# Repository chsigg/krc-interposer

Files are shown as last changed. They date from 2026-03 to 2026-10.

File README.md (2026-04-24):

# KRC Interposer

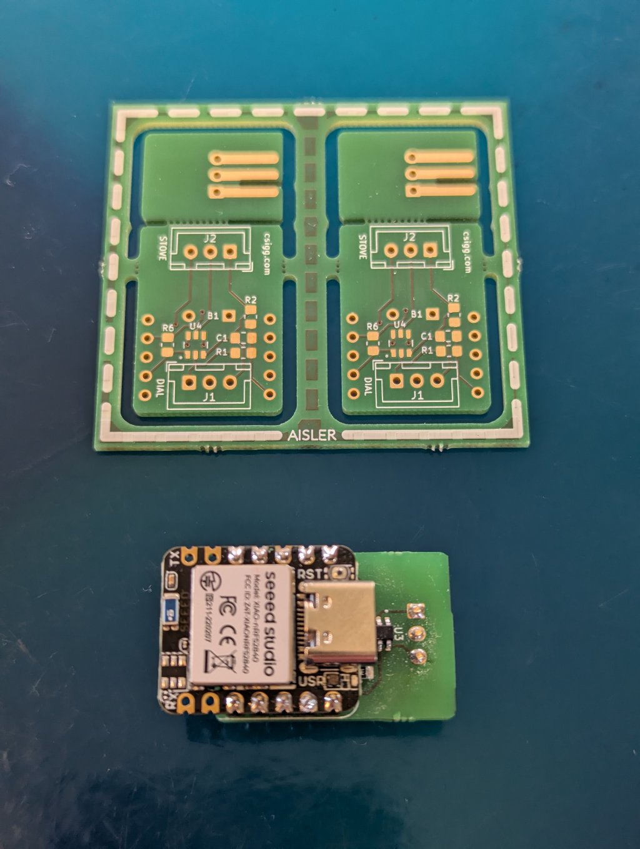
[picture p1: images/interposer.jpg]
KRC Interposer


The KRC Interposer is a hardware intermediary that converts a standard induction stove dial into a closed-loop temperature controller. It is designed for use with Kuhn Rikon Comfort (KRC) cookware, such as the Duromatic pressure cooker or Hotpan. The interposer intercepts the analog signal from the stove’s physical knob, connects to the cookware lid via Bluetooth Low Energy (BLE), and regulates the stove's power output to maintain a target temperature.

The system is built around the Seeed Studio XIAO nRF52840 microcontroller. It is designed to have no effect during standard stove operation, activating only when smart temperature control is initiated.

## Operating Modes

### Wake and Connection
Smart features are triggered by turning the dial to the stove's built-in **Boil Mode** (below 0). The resulting resistance change is detected by a companion PIC microcontroller, which then wakes the XIAO via serial communication (UART RX).

The microcontroller then takes control of the analog switch, routing its own filtered PWM output to the stove in place of the physical dial. It enters a scanning state to locate a Kuhn Rikon Comfort lid via BLE. Upon successful connection, the device emits an audible beep.

### Active Temperature Control
Once connected, the physical dial's positions are repurposed:
*   **Off:** Pauses heating and acts as an "Off" switch.
*   **1 to 9:** Maps to a target temperature range between 30°C and 120°C.

The interposer reads the current temperature from the BLE lid and uses a proportional-predictive thermal model (with feed-forward heat loss compensation) to simulate the required analog voltage to the stove. It automatically utilizes the stove's native hardware boost modes for rapid heating. A slew-rate limiter ensures smooth voltage transitions to prevent hardware faults on the stove's internal controller.

### Safety and Shutdown
*   **Signal Loss:** If the BLE connection drops, the interposer emits a warning beep and eventually reduces stove power to a safe minimum until the connection is restored.
*   **Power Off:** Turning the dial to **Off** initiates a 5-second shutdown timer. After this delay, the XIAO powers down completely, and the analog switch reconnects the physical dial to the stove.

### Telemetry (Optional)
The interposer concurrently operates as a BLE Peripheral. A [companion app](http://github.com/chsigg/krc-app) can connect to receive real-time telemetry, including measured temperature, target temperature, and diagnostic logs.

### Video of the interposer in action
KRC Interposer in action (https://www.youtube.com/watch?v=Ic5JpSSapok)

## Hardware Overview

The interposer board acts as a man-in-the-middle interface between a Miele stove and its physical 10kΩ potentiometer dial. It allows a Seeed Studio XIAO nRF52840 to either passively monitor the dial or actively override the signal to control the stove.

### Dial Interface

The physical dial on the stove functions as a potentiometer, outputting a variable analog voltage to the stove's control electronics:

*   **Off:** The signal line is left floating.
*   **1 to 9:** Standard heating power levels.
*   **Below 0 (Boil Mode):** Resistance drops to a minimum. The stove interprets this as a command to apply maximum power for a set duration before returning to the dial's indicated level.
*   **Above 9 (Boost Mode):** Activates discrete high-power boost levels.

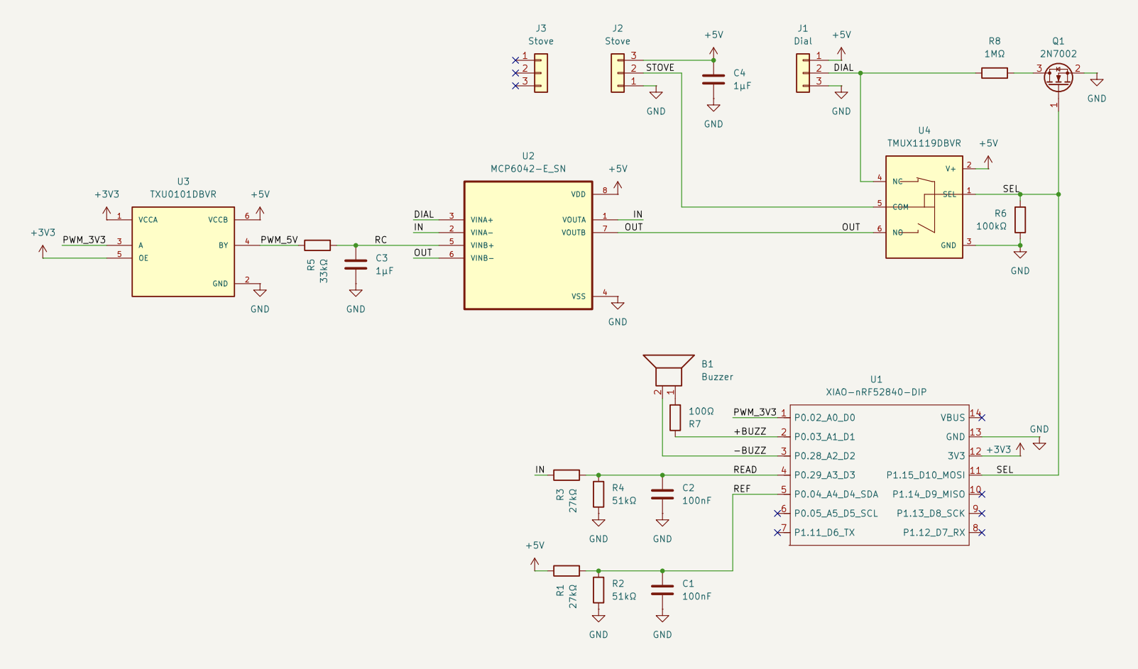
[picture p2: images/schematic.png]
Schematic


### Core Subsystems

*   **Signal Routing (TMUX1119):** A 5V SPDT analog switch toggles the stove's sensor input. In Bypass Mode (default), it connects the stove directly to the physical dial. In Control Mode, it connects the stove to the synthetic control signal.
*   **ADC Sensing:** Voltage dividers (27kΩ / 51kΩ) step the 5V dial and stove signals down to safe 3.3V levels for the XIAO's ADC. High-impedance values limit parasitic draw to ~30µA, as the stove's 5V line is a current-limited sensor reference (max ~1.5mA) and will collapse under standard loads.
*   **Synthetic Signal Generation (TXU0101 & MCP6042):** The XIAO generates a 3.3V PWM signal. A TXU0101 level shifter steps this up to 5V. An RC filter and an MCP6042 micropower op-amp buffer the signal into a clean analog DC voltage for the stove.
*   **Switched Pull-Down:** A pull-down resistor prevents the op-amp input from floating when the dial is turned off. An N-channel MOSFET disconnects this resistor during Bypass Mode to avoid tripping the stove's safety interlocks.
*   **Power Isolation:** The XIAO must be powered independently via USB. The stove's 5V reference rail cannot supply the current required for microcontroller boot or radio transmission.

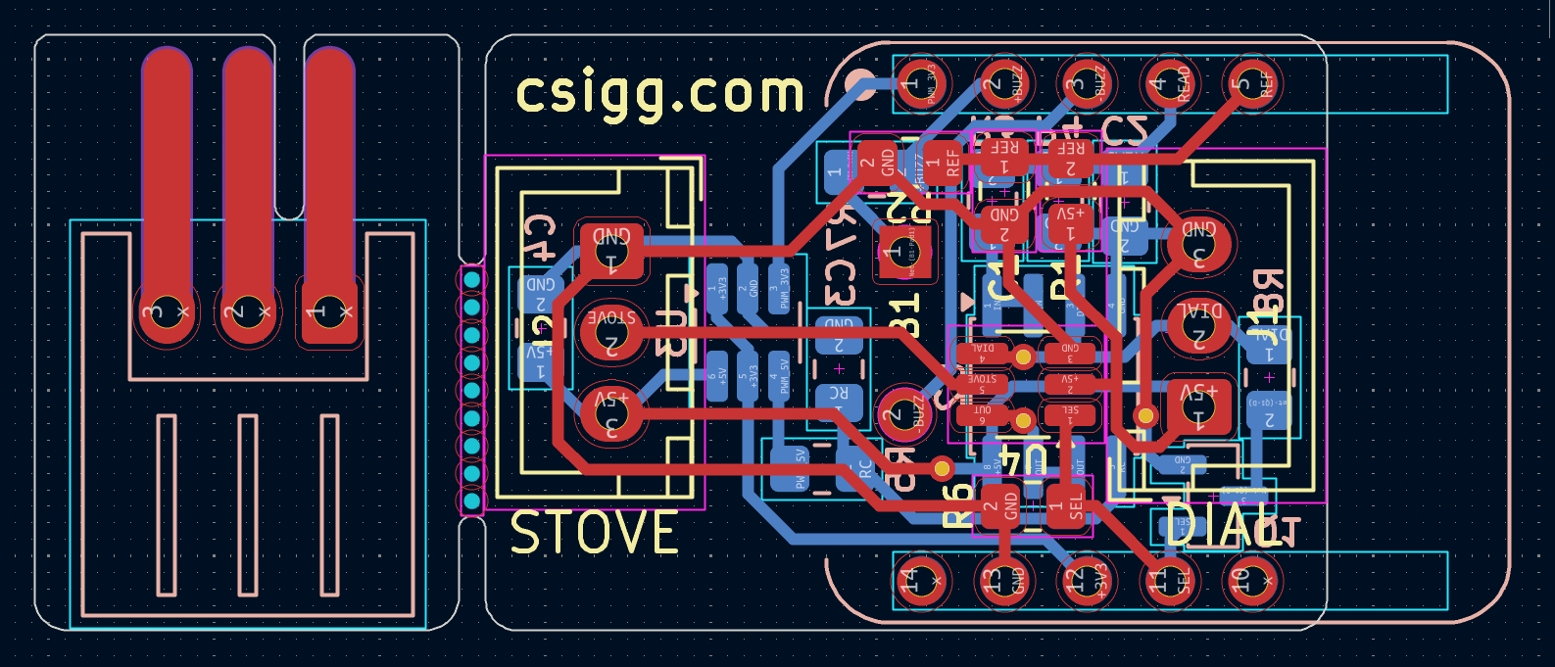
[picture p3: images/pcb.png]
PCB


## Development

The project is built using PlatformIO and the Arduino framework.

### Build
Compile the firmware for the XIAO nRF52840:
```bash
pio run
```

### Testing
Unit tests are implemented with `doctest` and `ArduinoFake` to run the logic modules natively on the host machine.
```bash
pio test -e native
```

## Software Architecture

The firmware enforces strict separation between high-level control logic and hardware interfaces to facilitate native testing.

*   **`StoveSupervisor`:** A state machine managing the high-level operational states (`SCANNING`, `CONNECTED`, `ACTIVE`, `DISCONNECTED`). It handles timers, user feedback, and logic for engaging hardware boost modes.
*   **`ThermalController`:** Implements the closed-loop temperature regulation using a proportional-predictive model and ambient heat loss compensation.
*   **`StoveActuator`:** Translates logical throttle requests into physical PWM signals. It includes a slew-rate limiter (`0.001/ms`) and minimum voltage clamping to maintain hardware stability on the stove's input line.
*   **`TrendAnalyzer`:** Buffers BLE temperature readings to calculate predicted future temperatures (compensating for system thermal lag) and the current rate of change.
*   **`BleThermometer` (BLE Central):** Scans for and connects to supported KRC lids, passing incoming temperature data to the `TrendAnalyzer`.
*   **`BleTelemetry` (BLE Peripheral):** Broadcasts internal state data and buffered logs to connected clients.
*   **Hardware Abstractions:** Interfaces like `DialSensor` and `StoveActuator` or 'Led' decouple the core logic from Arduino-specific functions, allowing execution against mock objects in the test suite.

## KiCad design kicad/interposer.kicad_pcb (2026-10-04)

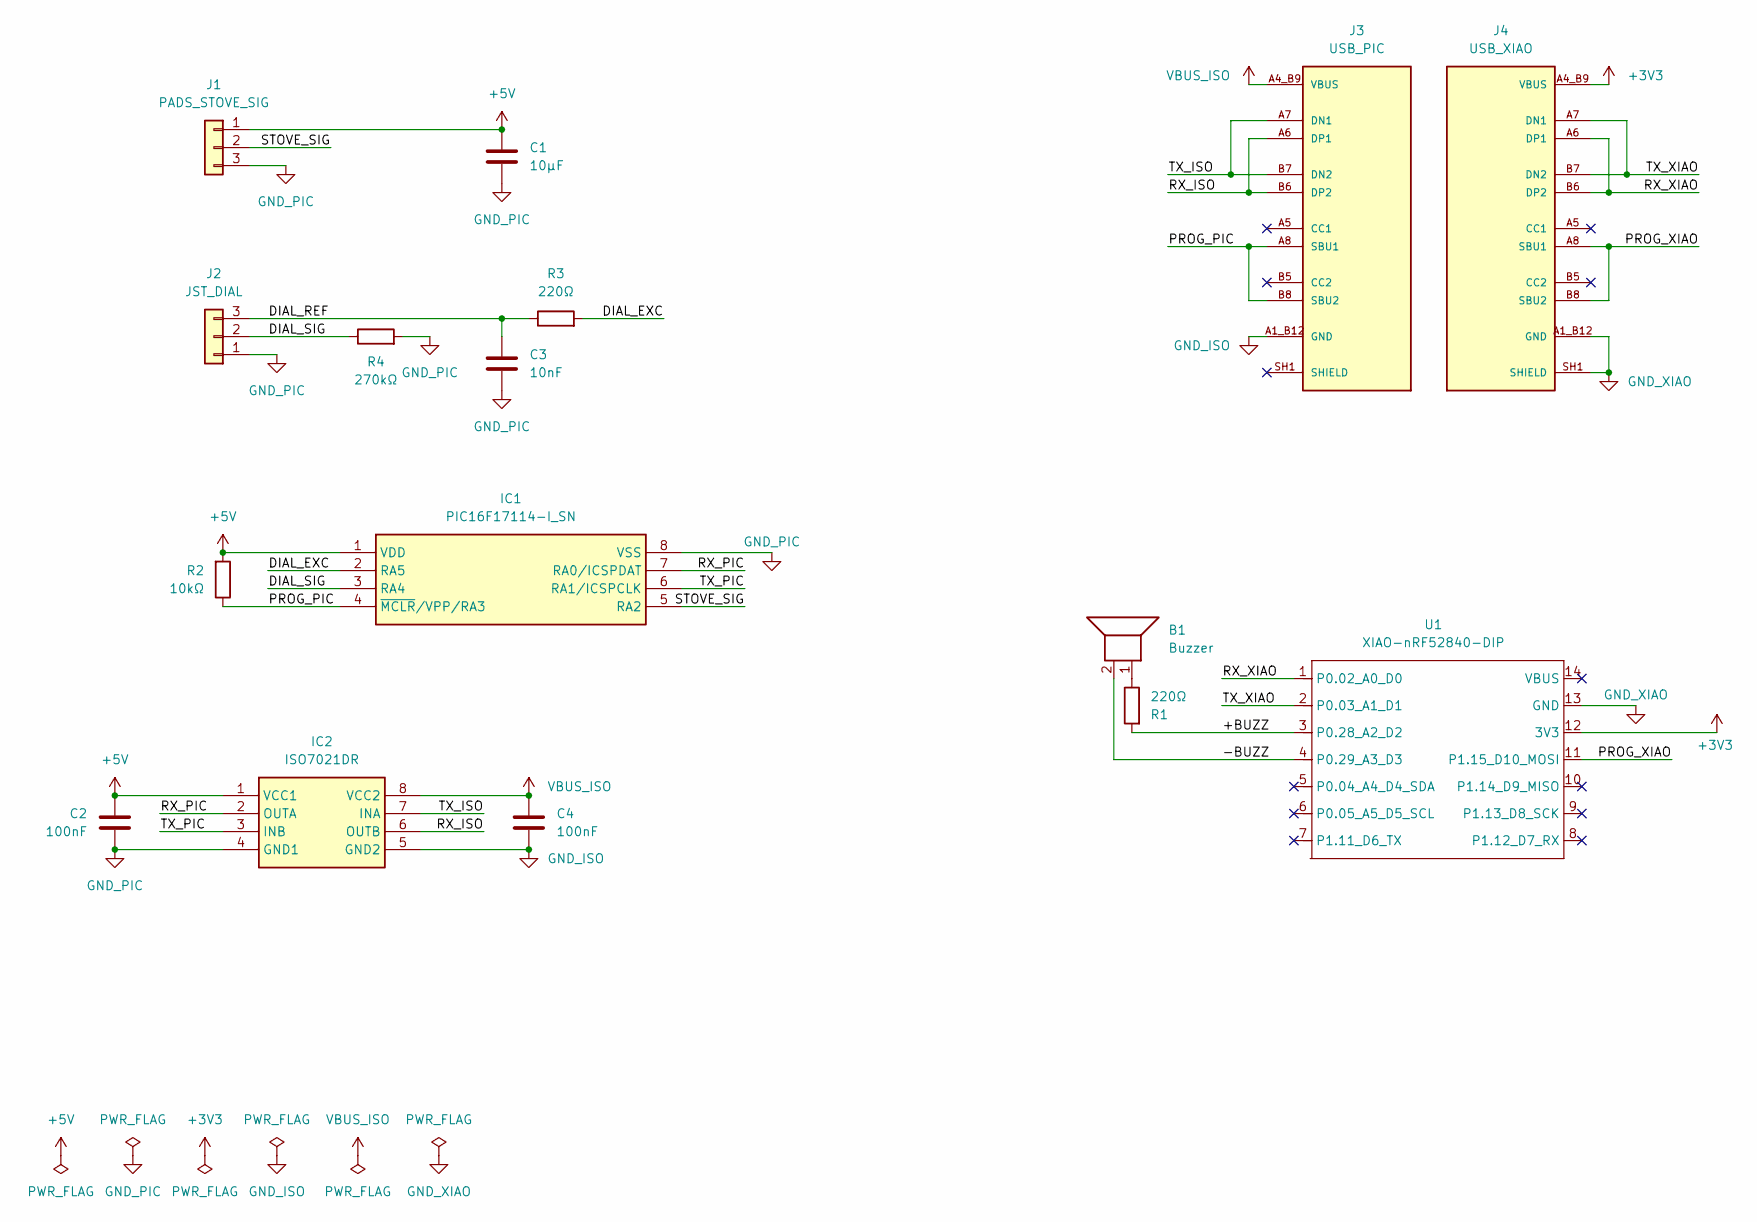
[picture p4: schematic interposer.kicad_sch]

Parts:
B1: Buzzer; Buzzer_Murata_PKLCS1212E
C1: 10µF; C_0805_2012Metric_Pad1.18x1.45mm_HandSolder
C2, C4: 100nF; C_0805_2012Metric_Pad1.18x1.45mm_HandSolder
C3: 10nF; C_0805_2012Metric_Pad1.18x1.45mm_HandSolder
IC1: PIC16F17114-I_SN; SOIC-8_3.9x4.9mm_P1.27mm; Manufacturer_Part_Number PIC16F17114-I/SN; Mouser Part Number 579-PIC16F17114-I/SN
IC2: ISO7021DR; SOIC-8_3.9x4.9mm_P1.27mm; Manufacturer_Part_Number ISO7021DR; Mouser Part Number 595-ISO7021DR
J1: PADS_STOVE_SIG; RAST 2.5 Pads
J2: JST_DIAL; JST_XH_S3B-XH-A_1x03_P2.50mm_Horizontal
J3: USB_PIC; SAMESKY_UJ20-C-H-G-SMT-P16-TR; PARTREV 1.0
J4: USB_XIAO; SAMESKY_UJ20-C-H-G-SMT-P16-TR; PARTREV 1.0
R1, R3: 220Ω; R_0805_2012Metric_Pad1.20x1.40mm_HandSolder
R2: 10kΩ; R_0805_2012Metric_Pad1.20x1.40mm_HandSolder
R4: 270kΩ; R_0805_2012Metric_Pad1.20x1.40mm_HandSolder
U1: XIAO-nRF52840-DIP

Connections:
+3V3: J4.A4_B9 (VBUS), J4.B4_A9 (VBUS), U1.12 (3V3)
+5V: C1.1, C2.1, IC1.1 (VDD), IC2.1 (VCC1), J1.1, R2.2
/+BUZZ: R1.2, U1.3 (P0.28_A2_D2)
/-BUZZ: B1.2, U1.4 (P0.29_A3_D3)
/DIAL_EXC: IC1.2 (RA5), R3.2
/DIAL_REF: C3.1, J2.3, R3.1
/DIAL_SIG: IC1.3 (RA4), J2.2, R4.1
/PROG_PIC: IC1.4 (~MCLR/VPP/RA3), J3.A8 (SBU1), J3.B8 (SBU2), R2.1
/PROG_XIAO: J4.A8 (SBU1), J4.B8 (SBU2), U1.11 (P1.15_D10_MOSI)
/RX_ISO: IC2.6 (OUTB), J3.A6 (DP1), J3.B6 (DP2)
/RX_PIC: IC1.7 (RA0/ICSPDAT), IC2.2 (OUTA)
/RX_XIAO: J4.A6 (DP1), J4.B6 (DP2), U1.1 (P0.02_A0_D0)
/STOVE_SIG: IC1.5 (RA2), J1.2
/TX_ISO: IC2.7 (INA), J3.A7 (DN1), J3.B7 (DN2)
/TX_PIC: IC1.6 (RA1/ICSPCLK), IC2.3 (INB)
/TX_XIAO: J4.A7 (DN1), J4.B7 (DN2), U1.2 (P0.03_A1_D1)
GND_ISO: C4.2, IC2.5 (GND2), J3.A1_B12 (GND), J3.A12_B1 (GND)
GND_PIC: C1.2, C2.2, C3.2, IC1.8 (VSS), IC2.4 (GND1), J1.3, J2.1, R4.2
GND_XIAO: J4.A1_B12 (GND), J4.A12_B1 (GND), J4.SH1 (SHIELD), J4.SH2 (SHIELD), J4.SH3 (SHIELD), J4.SH4 (SHIELD), U1.13 (GND)
unnamed: B1.1, R1.1
VBUS_ISO: C4.1, IC2.8 (VCC2), J3.A4_B9 (VBUS), J3.B4_A9 (VBUS)

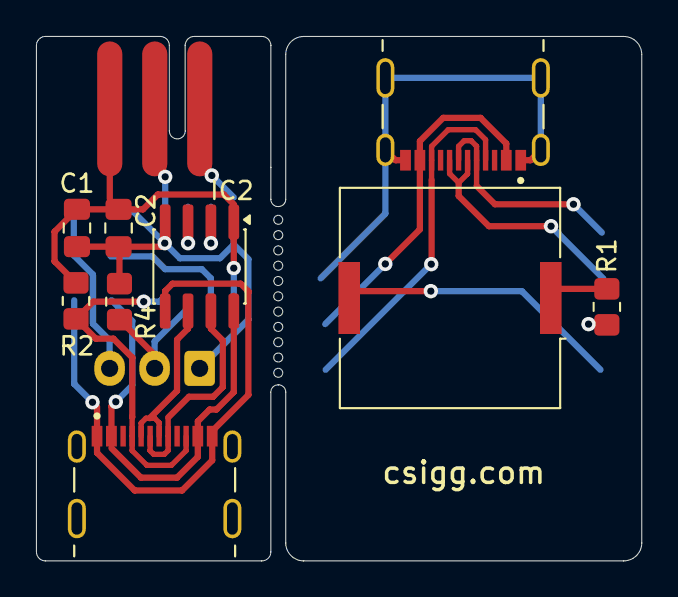
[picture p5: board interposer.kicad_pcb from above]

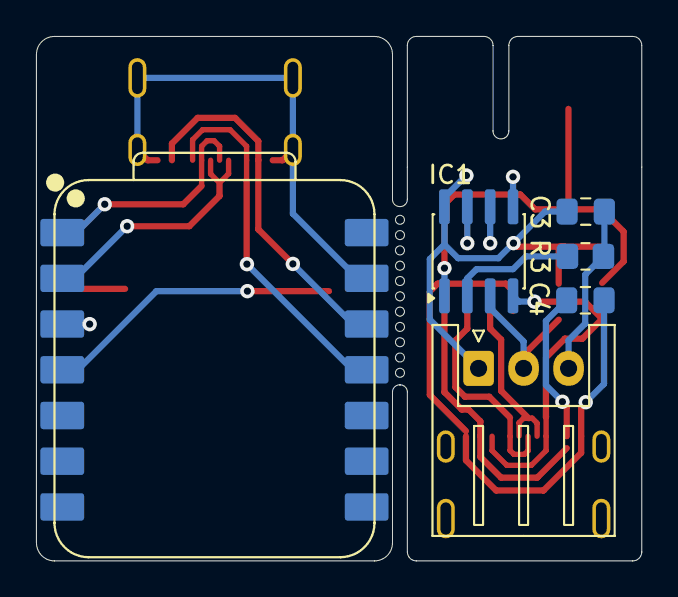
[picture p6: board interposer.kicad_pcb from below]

Board: 2 copper layers, 33.6 x 29.1 mm, 16 parts (6 on the bottom side), 21 nets.

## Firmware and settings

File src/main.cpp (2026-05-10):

#include <bluefruit.h>
#include <nrf_lpcomp.h>
#include <nrf_pwm.h>

#include "ArduinoBuzzer.h"
#include "ArduinoLed.h"
#include "ArduinoLogger.h"
#include "ArduinoUart.h"
#include "Beeper.h"
#include "BleTelemetry.h"
#include "BleThermometer.h"
#include "StoveController.h"
#include "StoveDial.h"
#include "StoveSupervisor.h"
#include "ThermalController.h"
#include "TimestampLogger.h"
#include "TrendAnalyzer.h"

void delayUs(uint32_t us) { delayMicroseconds(us); }

constexpr int kUartTxPin = D0;
constexpr int kUartRxPin = D1;
constexpr int kBuzzerPPin = A2;
constexpr int kBuzzerNPin = A3;

static void shutdown();

// --- Hardware Instantiation ---

// Tee stream for logging to Serial and BLE
BufferedLogger buffered_logger(1024);
ArduinoLogger arduino_logger(buffered_logger);
TimestampLogger timestamp_logger(arduino_logger);
Logger &Log = timestamp_logger;

// UART communication with PIC
ArduinoUart uart(kUartRxPin, kUartTxPin);

// Configuration
ThrottleConfig throttle_config;
ThermalConfig thermal_config;

uint32_t dial_off_start_ms = 0;

// Actuators
StoveController controller(uart, throttle_config);

// Sensors
StoveDial dial(uart, throttle_config);

// Feedback
ArduinoBuzzer buzzer(NRF_PWM3, kBuzzerPPin, kBuzzerNPin);
Beeper beeper(buzzer);
ArduinoLed red_led(LED_RED);
ArduinoLed green_led(LED_GREEN);

// Logic Modules
TrendAnalyzer analyzer;
ThermalController thermal_controller(analyzer, thermal_config);

// BLE Modules
BleThermometer thermometer(analyzer);
BleTelemetry telemetry(thermal_controller, analyzer, buffered_logger);

// Supervisor (bypassing is handled internally by uart)
StoveConfig stove_config;
StoveSupervisor supervisor(dial, controller, thermal_controller, beeper,
                           analyzer, stove_config, throttle_config);

void setup() {
  uart.begin();

  for (int pin : {D4, D5, D6, D7, D8, D9, D10}) {
    pinMode(pin, INPUT_PULLDOWN);
  }

  analogWriteResolution(ADC_RESOLUTION);

  red_led.begin();
  green_led.begin();
  green_led.set(1.0f);

  Serial.begin(115200);

  Bluefruit.configPrphConn(BLE_GATT_ATT_MTU_MAX, BLE_GAP_EVENT_LENGTH_DEFAULT,
                           BLE_GATTS_HVN_TX_QUEUE_SIZE_DEFAULT,
                           BLE_GATTC_WRITE_CMD_TX_QUEUE_SIZE_DEFAULT);
  Bluefruit.begin(1, 1);
  Bluefruit.autoConnLed(false);
  Bluefruit.setTxPower(8);
  Bluefruit.setName("KRC Interposer");

  buzzer.begin();
  beeper.beep(Beeper::Signal::POWER_ON);

  while (!Serial && millis() < 1000) {
    beeper.update();
    delay(10);
  }
  Log << "KRC Interceptor Starting...\n";

  thermometer.begin();
  telemetry.begin();
  green_led.set(0.0f);
}

void loop() {
  if (dial.isOff()) {
    if (millis() - dial_off_start_ms > 5000) {
      return shutdown();
    }
  } else {
    dial_off_start_ms = millis();
  }

  uart.update();
  thermometer.update();
  supervisor.update();
  red_led.set(thermal_controller.getPower());
  telemetry.update();
  delay(20);
}

static void shutdown() {
  red_led.set(1.0f);
  beeper.beep(Beeper::Signal::POWER_OFF);
  while (!beeper.isIdle()) {
    delay(10);
    beeper.update();
  }

  Log << "Powering off...\n";

  thermometer.end();
  telemetry.update();
  telemetry.end();
  uart.end();

  Serial.flush();
  Serial.end();

  for (auto pwm : {NRF_PWM0, NRF_PWM1, NRF_PWM2, NRF_PWM3}) {
    nrf_pwm_disable(pwm);
  }
  for (int pin : {kBuzzerPPin, kBuzzerNPin}) {
    pinMode(pin, INPUT_PULLDOWN);
  }
  for (int pin : {kUartTxPin, LED_RED, LED_GREEN, LED_BLUE}) {
    pinMode(pin, INPUT_PULLUP);
  }

  // Set up System OFF Boot trigger based on UART RX Start Bit (High-to-Low)
  nrf_gpio_cfg_sense_input(g_ADigitalPinMap[kUartRxPin], NRF_GPIO_PIN_PULLUP,
                           NRF_GPIO_PIN_SENSE_LOW);
  sd_power_system_off();
}

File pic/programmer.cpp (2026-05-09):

#include <Arduino.h>
#include <Adafruit_TinyUSB.h>
#include <iterator>
#include "firmware_data.h"

// Hardware Definitions
const int PIN_MCLR = D10;
const int PIN_ICSPDAT = D0;
const int PIN_ICSPCLK = D1;

// Microchip ICSP Timing Specs (PIC16F17114)
const uint32_t T_ENTH_US = 500;
const uint32_t T_DLY_US = 100;
const uint32_t T_ERAB_MS = 15;
const uint32_t T_PINT_MS = 10;
const uint32_t T_CLOCK_US = 5;

// --- Low-Level Bit-Bang Helpers ---

// Explicit delays to satisfy PIC timing parameter constraints.
inline void tickDelay() {
    delayMicroseconds(T_CLOCK_US);
}

void bitBangWrite(uint32_t data, int num_bits) {
    // Set as output to drive the PIC
    pinMode(PIN_ICSPDAT, OUTPUT);

    // PIC Expects MSb First for command and payload data fields
    for (int i = num_bits - 1; i >= 0; i--) {
        digitalWrite(PIN_ICSPDAT, (data >> i) & 0x01);

        // Data changes on rising edge, latched on falling edge.
        // Verified timing: PIC samples strictly during stable HIGH period.
        tickDelay();
        digitalWrite(PIN_ICSPCLK, HIGH);
        tickDelay();
        digitalWrite(PIN_ICSPCLK, LOW);
    }

    // Ensure line returns to safe state
    digitalWrite(PIN_ICSPDAT, LOW);
}

uint32_t bitBangRead(int num_bits) {
    uint32_t val = 0;

    // Set to high-impedance input to let the PIC drive
    pinMode(PIN_ICSPDAT, INPUT);

    // Extra explicit turnaround delay to ensure bus yields
    delayMicroseconds(5);

    for (int i = num_bits - 1; i >= 0; i--) {
        tickDelay();
        digitalWrite(PIN_ICSPCLK, HIGH);

        // Standard consensus: Sample strictly inside the HIGH clock phase.
        // We delay slightly into the High phase to sample at dead-center stability.
        tickDelay();

        if (digitalRead(PIN_ICSPDAT)) {
            val |= (1UL << i);
        }

        digitalWrite(PIN_ICSPCLK, LOW);
    }

    // Reclaim the line for subsequent commands
    pinMode(PIN_ICSPDAT, OUTPUT);
    digitalWrite(PIN_ICSPDAT, LOW);

    return val;
}

// --- Core ICSP Primitives ---

void sendCommand(uint8_t cmd) {
    bitBangWrite(cmd, 8);
    delayMicroseconds(T_DLY_US);
}

void sendPayload(uint16_t data) {
    // 24-bit frame: [Start=0 (bit 23)] [Pad=000000 (bits 22-17)] [Data=16 bits (bits 16-1)] [Stop=0 (bit 0)]
    // The data is explicitly 16 bits, left-shifted by 1 to make space for the stop bit.
    // This construction preserves Bit 15 of the address (e.g. 0x8000 range), which previous code truncated.
    uint32_t frame = (static_cast<uint32_t>(data) & 0xFFFF) << 1;

    bitBangWrite(frame, 24);
    delayMicroseconds(T_DLY_US);
}

uint16_t readPayload() {
    // Read 24-bit frame from the device
    uint32_t frame = bitBangRead(24);

    // Extract the 16 bits contained in frame bits 16 through 1.
    // The 14-bit payload is safely within these 16 bits.
    uint16_t data = (frame >> 1) & 0xFFFF;

    delayMicroseconds(T_DLY_US);
    return data;
}

// --- Programming State Machine ---

bool enterLvp() {
    digitalWrite(PIN_ICSPCLK, LOW);
    digitalWrite(PIN_ICSPDAT, LOW);
    pinMode(PIN_ICSPCLK, OUTPUT);
    pinMode(PIN_ICSPDAT, OUTPUT);

    // Ensure MCLR holds PIC in reset
    digitalWrite(PIN_MCLR, LOW);
    delayMicroseconds(T_ENTH_US);

    // Shift in 32-bit LVP Key: 0x4D434850 strictly MSb First
    bitBangWrite(0x4D, 8);
    bitBangWrite(0x43, 8);
    bitBangWrite(0x48, 8);
    bitBangWrite(0x50, 8);

    delayMicroseconds(T_DLY_US);
    return true;
}

void exitLvp() {
    digitalWrite(PIN_MCLR, HIGH);
}

void bulkErase() {
    sendCommand(0x80);      // Load PC Address
    sendPayload(0x0000);    // Point to Flash

    sendCommand(0x18);      // Bulk Erase
    sendPayload(0x000A);    // Bit 1 = Flash, Bit 3 = Config

    delay(T_ERAB_MS);
}

void writeMemory(uint16_t start_addr, const uint16_t* data, size_t count, uint32_t row_size) {
    sendCommand(0x80);
    sendPayload(start_addr);

    for (size_t i = 0; i < count; i++) {
        bool end_of_row = (i + 1) % row_size == 0;
        sendCommand(end_of_row ? 0x00 : 0x02);
        sendPayload(data[i]);

        if (end_of_row) {
            sendCommand(0xE0); // Begin Internally Timed Programming
            delay(T_PINT_MS);

            if (i < count - 1) {
                sendCommand(0xF8); // Increment Address
            }
        }
    }
}

void verifyMemory(uint16_t start_addr, const uint16_t* data, size_t count) {
    sendCommand(0x80);
    sendPayload(start_addr);

    for (size_t i = 0; i < count; i++) {
        sendCommand(0xFE);  // Read Data and Increment PC
        uint16_t read_val = readPayload();
        uint16_t current_addr = start_addr + i;

        if (read_val != data[i]) {
            Serial.printf("Verify Failed at 0x%04X: Expected 0x%04X, Got 0x%04X\n", current_addr, data[i], read_val);
            return;
        }
    }
    Serial.printf("Verification Successful!\n");
}

// --- Arduino Framework ---

void setup() {
    Serial.begin(115200);
    while(!Serial);

    pinMode(PIN_MCLR, OUTPUT);
    digitalWrite(PIN_MCLR, HIGH); // Hold PIC in normal run mode

    pinMode(PIN_ICSPCLK, OUTPUT);
    digitalWrite(PIN_ICSPCLK, LOW);
    pinMode(PIN_ICSPDAT, OUTPUT);
    digitalWrite(PIN_ICSPDAT, LOW);

    Serial.println("Starting PIC LVP Programming Sequence...");

    enterLvp();

    // Check connection by reading Device ID (at PC 0x8006)
    sendCommand(0x80);
    sendPayload(0x8006);
    sendCommand(0xFC);
    uint16_t dev_id = readPayload();

    if (dev_id != 0x30DB) {
        Serial.printf("Error: Invalid Device ID: 0x%04X\n", dev_id);
        exitLvp();
        return;
    }

    Serial.println("Erasing...");
    bulkErase();

    Serial.println("Writing Flash...");
    writeMemory(0x0000, kProgramData, std::size(kProgramData), 32);

    Serial.println("Writing Config...");
    writeMemory(0x8007, kConfigData, std::size(kConfigData), 1);

    Serial.println("Verifying Flash...");
    verifyMemory(0x0000, kProgramData, std::size(kProgramData));

    Serial.println("Verifying Config...");
    verifyMemory(0x8007, kConfigData, std::size(kConfigData));

    exitLvp();
    Serial.println("Done.");
}

void loop() {
    // Programmer is idle
}

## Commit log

2025-12-03 Switch analog reading to float and fix logic
    [StoveActuatorTest.cpp]
2025-12-03 Fix arduino build
2025-12-03 Some bug fixes but mostly debugging printfs.
    [main.cpp]
2025-12-06 Distinguish 'level' to 'level', 'throttle' and 'position'. Fix Beeper/Blinker states.
    [StoveActuatorTest.cpp, main.cpp]
2025-12-13 Allow bonding, fix service vs char initialization order
    [main.cpp]
2025-12-14 Make TrendAnalyzer and ThermalController thread safe.
2025-12-15 Use LED for digipot testing
2025-12-17 Fix millis() overflow issue in Blinker and Beeper.
2025-12-20 Change to i2c potentiometer.
2025-12-22 Move actuator initialization to setup.
2025-12-22 Add KiCad model
    [interposer.kicad_pcb, interposer.kicad_sch]
2025-12-23 Update KiCad to two layers
    [interposer.kicad_pcb, interposer.kicad_sch]
2025-12-24 Don't advertise intermediate temperature when there is no data.
2025-12-26 Use built-in LEDs for feedback.
2025-12-30 Add a DISCONNECTED state and fix various state transition things.
    [StoveActuatorTest.cpp, main.cpp]
2026-01-30 Hook red led to input reading
2026-01-31 Fix DFU (MTU negotiation) Simplify boost activation
    [StoveActuatorTest.cpp, main.cpp]
2026-02-02 Adjust BLE power and timings.
2026-02-03 Add poweroff()
2026-03-02 Simplify stove control logic and state machine
    - Refactor StoveActuator to use AnalogWritePin and remove bypass logic.
    - Streamline StoveSupervisor by removing redundant states (SLEEP, COOLDOWN, ACTIVATING).
    - Add power-off callback support to StoveSupervisor.
    - Remove the unused Blinker component.
2026-03-02 Remove green LED when bypass is active
2026-03-02 Remove red LED to show the dial reading
2026-03-03 Move bypass pin and only take over control once lid is connected.
2026-03-03 Add LED feedback
2026-03-03 Add power-on/off beep, remove StoveDial averaging.
2026-03-04 Move blue led to BleThermometer
2026-03-04 Fix wakup pin choice
    [main.cpp]
2026-03-05 Moving missing temp data to BleThermometer::connected
    [main.cpp]
2026-03-05 Disable pwm before shutdown
2026-03-06 Disconnect BLE when switching to idle.
2026-03-09 Measured ThrottleConfig values
2026-03-21 Set power to zero when dial is zero. Plus some printing and formatting changes.
2026-03-23 Replace BLEUart with indicated custom service
    [main.cpp]
2026-03-28 Slewed PWM output.
2026-03-29 Update KiCad
    [interposer.kicad_pcb, interposer.kicad_sch]
2026-04-24 Move slew and bypass mode from XIAO to PIC
    Communication & Safety Refactor:
    - Master-Slave Protocol: The PIC (interposer.c) has been refactored to be a slave device, responding only to packets from the XIAO (except for a one-shot wake-up packet). The XIAO (ArduinoUart.h) is 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
    - Parity Support: Hardware Even Parity is enabled on the XIAO, and software-emulated Even Parity (using 9-bit mode) is implemented on the PIC.
    - Safe Output Logic: The PIC uses a two-state model (MODE_PASSTHROUGH and MODE_OVERRIDE) and enforces that the stove never appears off when the dial is on (clamping override values to a minimum of 25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
    - Shutdown Sequence: The 5-second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
2026-04-30 PIC firmware build fixes
    [firmware.c]
2026-05-01 Change programmer pin assignment
2026-05-06 Switch programmer to bit banging.
2026-05-07 Swap PIC TX/RX pins
    [firmware.c]
2026-05-09 Interrupt-free firmware
2026-05-10 Fix floating tx pin during power-off, waking up the xiao.
    [main.cpp]
2026-05-11 Add PIC UART frame error detection
    [firmware.c]
2026-05-15 Lowering clock to 500kHz, trying to fix Op-Amp output (which is not exposed on the 8-pin variant, but submitting before changing for completeness)
    [firmware.c]
2026-05-16 Connect DAC directly to RA2, without the Op-Amp.
    The 8 pin version does now allow Op-Amp output.
    Some trickery is needed for low vs high DAC ref range.
    Power consumption is still a bit high at 850uA.
2026-05-18 Optimize PIC active power to 338uA using native MFINTOSC (500 kHz) and PMD, refactor Master UART to non-blocking 9600
2026-05-18 Enable PIC Brown-out Reset (BOD) config for essential hardware protection
    [firmware.c]
2026-05-20 Fix clock.
    Correct NOSC value for MFINTOSC is 0b011, but that runs at 1.1mA.
    Switched to HFINTOSC again, running at 730uA.
    [firmware.c]
2026-10-04 Read ADC every 10th iteration
